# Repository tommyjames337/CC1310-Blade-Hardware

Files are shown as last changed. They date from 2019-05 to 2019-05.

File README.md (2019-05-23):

# CC1310-Blade-Hardware README

This repository contains the crucial design files for the CC1310 Blade (Rev D). Note that the Rev D board is functionally
identical to the Rev C board. It will work with all CC1310 Blade Rev C demo projects.

The files in this project should be organized accordingly in order to open the project correctly in KiCad:

1) Place CC1310_Dev_Board_D into desired directory.

2) Stock.zip and CC1310.zip should be unpacked into the same directory that CC1310_Dev_Board_D was placed into.

After the project is correctly opened, you may have to correct the references to the footprint and schematic symbol files. Once these references are corrected, you may create gerber files and order PCBs from your favorite manufacturer.

The repository for CC1310 Blade software demos can be found here: https://github.com/mprost/CC1310-Blade-Demos

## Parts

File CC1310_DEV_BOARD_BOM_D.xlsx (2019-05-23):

Texas Instruments & University of Texas at Austin |  |  |  | Created: | 2019-05-01
Assembly BOM for CC1310_DEV_BOARD |  |  |  | Revision: | D
Bill of Materials
Item | Ref | Qty | Description | Mfg | Part Number | Price/unit | Price of Qty
1 | C2 | 1 | CAPACITOR, CERAMIC C0G/NP0, 3.3pF, 50V, -0.25pF/+0.25pF, -55DEGC/+125DEGC, 0402, SMD | Murata | GRM1555C1H3R3CA01J | $0.10000 | $0.10000
2 | C3 | 1 | DNI CAP |  |  |  | $0.00000
3 | C4, C6 | 2 | CAPACITOR, CERAMIC C0G/NP0, 12pF, 50V, -5%/+5%, -55DEGC/+125DEGC, 0402, SMD | Murata | GRM1555C1H120JA01D | $0.10000 | $0.20000
4 | C5 | 1 | CAP CER 330PF 50V X7R 0402 | Murata | GRM155R71H331MA01D | $0.19000 | $0.19000
5 | C1, C7, C8, C9, C11, C14, C15, C16 | 8 | CAP CER 0.1UF 6.3V X5R 0402 | Murata | GRM152R60J104KE19D | $0.24000 | $1.92000
6 | C10 | 1 | CAP CER 1UF 10V X7S 0402 | Murata | GCM155C71A105KE38D | $0.18000 | $0.18000
7 | C12, C13 | 2 | CAP CER 22UF 6.3V X5R 0402 | Samsung Electro-Mechanics | CL05A226MQ5N6J8 | $0.56000 | $1.12000
8 | C17, C19 | 2 | CAP CER 2.2UF 6.3V X6S 0402 | Murata | GRM155C80J225KE95J | $0.13000 | $0.26000
9 | C18 | 1 | CAP CER 15PF 50V C0G/NP0 0402 | Murata | GJM1555C1H150JB01D | $0.29000 | $0.29000
10 | C20 | 1 | CAP CER 100PF 50V 0402 | Murata | GCM1555C1H101FA16D | $0.13000 | $0.13000
11 | C21, C22 | 2 | CAP CER 10UF 6.3V 0402 | Murata | GRM155C60E106ME16D | $0.20000 | $0.40000
12 | U3 | 1 | TVS DIODE 5.5V 6SON | Texas Instruments | TPD4E004DRYR | $0.62000 | $0.62000
13 | D1 | 1 | Red 630nm LED Indication - Discrete 2V 0603 (1608 Metric) | ROHM Semiconductor | SML-P12U2TT86R | $0.52000 | $0.52000
14 | D2, D3 | 2 | Green 560nm LED Indication - Discrete 2V 0603 (1608 Metric) | ROHM Semiconductor | SML-P13PTT86R | $0.57000 | $1.14000
15 | D4 | 1 | DIODE SCHOTTKY 20V 1A SOD123FL | ON Semiconductor | MBR120VLSFT1G | $0.39000 | $0.39000
16 | D5 | 1 | Orange 560nm LED Indication - Discrete 2V 0603 (1608 Metric) | ROHM Semiconductor | SML-P12DTT86R | $0.42000 | $0.42000
17 | D6 | 1 | Board Mount Temperature Sensors Low VTG Prec Vout 2.7-5.5V | Analog Devices | TMP36GT9Z | $1.40000 | $1.40000
18 | J1 | 1 | HEADER 16 PIN SIL VERTICAL SOCKET TIN | Harwin | M20-7821642 | $1.99000 | $1.99000
19 | J2 | 1 | HEADER 12 PIN SIL VERTICAL SOCKET TIN | Harwin | M20-7821246 | $1.42000 | $1.42000
20 | J3 | 1 | HEADER 4 PIN SIL VERTICAL SOCKET TIN | Harwin | M20-7820446 | $0.78000 | $0.78000
21 | J4 | 1 | .050" X .050 TERMINAL STRIP | SAMTEC | FTSH-105-01-F-DV-K-TR | $2.07400 | $2.07400
22 | J5 | 1 | CONNECTOR, USB, FEMALE, RIGHT ANGLE, 1 ROW, 5 PINS, PITCH 0.65mm, SMD | Molex, LLC | 1051640001 | $0.46304 | $0.46304
23 | J6 | 1 | CONN JSC RCPT STR 50 OHM SMD | Murata | MM5829-2700RJ4 | $0.63000 | $0.63000
24 | J7 | 1 | JST-PH Battery Connector for Li-Ion Batteries | Adafruit | 1769 | $0.75000 | $0.75000
25 | J8 | 1 | Coin Cell Battery Holders SFC MNT FOR CR1220 | Renata | SMTU1220-LF | $0.83000 | $0.83000
26 | L1 | 1 | FIXED IND 18NH 350MA 460 MOHM | Murata | LQG15HS18NJ02D | $0.10000 | $0.10000
27 | L2 | 1 | DNI IND |  |  |  | $0.00000
28 | L3 | 1 | TRANSFORMER, RF, BALUN, 770MHz TO 928MHz, UNBALANCED:50 Ohm, SMD | JOHANSON TECHNOLOGY | 0850BM14E0016 | $0.55000 | $0.55000
29 | L4 | 1 | FERRITE BEAD 1.5 KOHM 0603 1LN | Murata | BLM18HE152SN1D | $0.21000 | $0.21000
30 | L5 | 1 | FIXED IND 6.8UH 550MA 250 MOHM | TDK | MLZ2012N6R8LT000 | $0.14000 | $0.14000
31 | R1, R2, R14 | 3 | RES SMD 180 OHM 5% 1/16W 0402 | Vishay Dale | CRCW0402180RJNED | $0.10000 | $0.30000
32 | R3, R4 | 2 | DNI RES |  |  |  | $0.00000
33 | R5 | 1 | RES SMD 2.2K OHM 5% 1/5W 0402 | Vishay Dale | CRCW04022K20JNEDHP | $0.14000 | $0.14000
34 | R6, R8 | 2 | RES 3.3K OHM 5% 1/16W 0402 | Vishay Dale | CRCW04023K30JNEDC | $0.10000 | $0.20000
35 | R7, R10, R17 | 3 | RES SMD 100K OHM 5% 1/16W 0402 | Vishay Dale | CRCW0402100KJNEDC | $0.10000 | $0.30000
36 | R9, R13 | 2 | RES SMD 100 OHM 5% 1/16W 0402 | Vishay Dale | CRCW0402100RJNEDC | $0.10000 | $0.20000
37 | R11 | 1 | RES SMD 51K OHM 5% 1/16W 0402 | Vishay Dale | CRCW040251K0JNED | $0.10000 | $0.10000
38 | R12 | 1 | RES SMD 30K OHM 5% 1/16W 0402 | Vishay Dale | CRCW040230K0JNED | $0.10000 | $0.10000
39 | R15, R16 | 2 | DNI RES SMD 0 OHM 5% 1/16W 0402 | Vishay Dale |  |  | $0.00000
40 | R18 | 1 | RES SMD 274 OHM 5% 1/10W 0402 | TE Connectivity | RP73PF1E274RBTDF | $0.26000 | $0.26000
41 | R19 | 1 | RES SMD 10K OHM 5% 1/16W 0402 | Vishay Dale | CRCW040210K0JNEDC | $0.10000 | $0.10000
42 | SW1, SW2 | 2 | Switch, Tact 6mm SMT, 160gf | Omron | B3U-1000P | $1.00000 | $2.00000
43 | U1 | 1 | IC, Microcontroller, Texas CC1310, 128kB, 1.8V to 3.8V, VQFN48-EP, SMD | Texas Instruments | CC1310F128RGZ | $6.65000 | $6.65000
44 | U2 | 1 | IC, ANALOG, ULTRALOW-NOISE, HIGH PSRR, FAST, RF, 1A LOW-DROPOUT LINEAR REGULATORS, VIN:2.7V TO 5.5V, VOUT:1.2V TO 5.5V, SON8, SMD | Texas Instruments | TPS79601DRBR | $3.09000 | $3.09000
45 | U4 | 1 | TVS DIODE 5.5V 8UQFN | Texas Instruments | TPD6E004RSER | $0.65000 | $0.65000
46 | U5 | 1 | IC FLASH 8M SPI 33MHZ 8USON | Macronix | MX25R8035FZUIL0 | $1.13000 | $1.13000
47 | U6 | 1 | Battery Management Charge mgnt contr | Microchip Technology | MCP73831T-2ACI_OT | $0.57000 | $0.57000
48 | Y1 | 1 | CRYSTAL 32.7680KHZ 7.0PF SMT | EPSON | FC-135R 32.7680KA-AG3 | $0.59000 | $0.59000
49 | Y2 | 1 | CRYSTAL 24.0000MHZ 9PF SMD | EPSON | TSX-3225 24.0000MF15X-AC3 | $0.36000 | $0.36000
50 |  | 1 | PCB (0.9” X 2”) (BLANK) | JLCPCB |  | $2.00000 | $2.00000
51 |  | 1 | Lithium Ion Polymer Battery - 3.7v 100mAh | Adafruit | 1570 | $5.95000 | $5.95000
52 |  | 1 | CR1220 Coin Cell Battery | Murata | CR1220 | $1.22000 | $1.22000
 | TOTAL |  |  |  |  |  | $43.90704

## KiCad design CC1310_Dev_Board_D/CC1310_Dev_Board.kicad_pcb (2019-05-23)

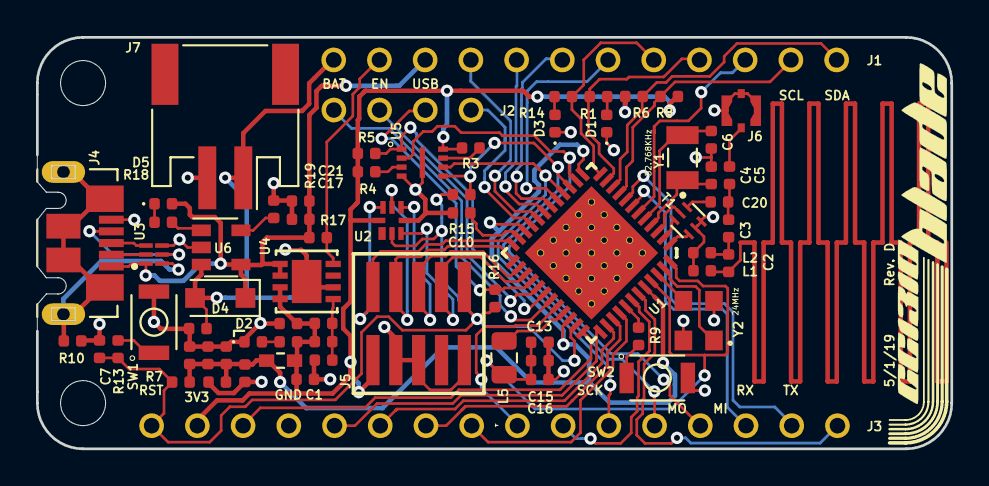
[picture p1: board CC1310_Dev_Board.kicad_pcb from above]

Board: 2 copper layers, 50.8 x 22.9 mm, 71 parts (1 on the bottom side), 69 nets.

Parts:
C1: 0.1uF; C_0402_1005Metric
C2: 3.3pF; C_0402_1005Metric
C3: DNM_0402; C_0402_1005Metric
C4, C6: 12pF; C_0402_1005Metric
C5: 330pF; C_0402_1005Metric
C7, C8, C9, C11, C14, C15, C16: 100nF; C_0402_1005Metric
C10: 1uF; C_0402_1005Metric
C12, C13: 22uF; C_0402_1005Metric
C17, C19: 2.2uF; C_0402_1005Metric
C18: 15pF; C_0402_1005Metric
C20: 100pF; C_0402_1005Metric
C21, C22: 10uF; C_0402_1005Metric
D1: SML-P12U2TT86R; LED_0402_1005Metric
D2, D3: SML-P13PTT86R; LED_0402_1005Metric
D4: MBR120; D_SOD-123F
D5: SML-P12DTT86R; LED_0402_1005Metric
J1: 68685-312LF; 68685-312LF-BLADE
J2: 68685-304LF; 68685-304LF-BLADE
J3: 68685-316LF; 68685-316LF-BLADE
J4: 105164-0001; MOLEX_105164-0001
J5: SAMTEC-FTSH-105-01-X-DV
J6: MM5829-2700RJ4; MURATA_MM5829-2700RJ4
J7: JST-PH; JST_PH_S2B-PH-SM4-TB_1x02-1MP_P2.00mm_Horizontal
J8: SMTU1220-LF; SMTU1225LF
L1: 18nH; L_0402_1005Metric
L2: DNM; L_0402_1005Metric
L4: BLM18HE152SN1D; INDC1608X95
L5: 6.8µH; L_0805_2012Metric
MH1, MH2: MountingHole; MountingHole_2.5mm
R1, R2, R14: 180; R_0402_1005Metric
R3, R4: DNI; R_0402_1005Metric
R5: 2.2K; R_0402_1005Metric
R6, R8: 3.3K; R_0402_1005Metric
R7, R10, R17: 100K; R_0402_1005Metric
R9, R13: 100; R_0402_1005Metric
R11: 51K; R_0402_1005Metric
R12: 30K; R_0402_1005Metric
R15, R16: 0; R_0402_1005Metric
R18: 274; R_0402_1005Metric
R19: 10K; R_0402_1005Metric
SW1, SW2: B3U-1000P; SW_B3U-1000P
T1: 0850BM14E0016T; INDCAF50P160X80X70-6N
U1: CC1310F64RGZT; QFN50P700X700X100-49N
U2: TPD6E004RSER
U3: TPD4E004DRYR
U4: TPS79601DRBR
U5: MX25R8035FZUIL0; USON-8L
U6: MCP73831T-2ACI_OT; SOT-23-5
Y1: FC-135R_32.7680KA-AG0; XTAL_FC-135R_32.7680KA-AG0
Y2: 24MHz; OSCSC320X250X100N

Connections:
AIO_23: J3.A3, U1.36
AIO_24: J3.A5, U1.37
AIO_25: J3.A6, U1.38
AIO_26: J3.A7, U1.39
AIO_27: J3.A8, U1.40
CC1310_RESET: C7.2, J3.A1, J5.10, R7.1, R13.2, R15.2, R16.2, U1.35, U2.2
CC1310_TCK: J5.4, U1.25, U2.6
CC1310_TMS: J5.2, U1.24, U2.7
CC1310_VDD: C1.1, C18.1, C19.1, J3.A2, J5.1, L4.1, R2.2, R3.1, R4.1, R5.1, R6.2, R8.2, R11.1, U2.8, U4.3, U4.4, U5.8
DIO_1: J1.A10, U1.6
DIO_2_UART_RX: J3.A14, U1.7
DIO_3_UART_TX: J3.A15, U1.8
DIO_4_SCL: J1.A11, R8.1, U1.9
DIO_5_SDA: J1.A12, R6.1, U1.10
DIO_8_MISO: J3.A13, U1.14, U5.2
DIO_9_MOSI: J3.A12, R15.1, U1.15, U5.5
DIO_10_SCLK: J3.A11, U1.16, U5.6
DIO_11: J1.A7, U1.17
DIO_12: J1.A6, U1.18
DIO_13: J1.A5, U1.19
DIO_14: J1.A4, U1.20
DIO_15: J2.A1, U1.21
DIO_16: J5.6, U1.26, U2.5
DIO_17: J5.8, U1.27, U2.3
DIO_18: J2.A2, R16.1, U1.28
DIO_19: J2.A3, U1.29
DIO_20: R5.2, U1.30, U5.1
DIO_21: J2.A4, U1.31
DIO_22: J3.A9, U1.32
DIO_29: J3.A10, U1.42
DIO_30: J3.A16, U1.43
EN: J1.A2, R17.1, U4.8
GND: C1.2, C4.1, C6.1, C7.1, C8.2, C9.2, C10.2, C11.2, C12.2, C13.2, C14.2, C15.2, C16.2, C17.2, C19.2, C21.2, C22.2, D1.1, D2.1, D3.1, J3.A4, J4.5, J5.3, J5.5, J5.9, J6.2, J6.3, J6.4, J7.2, J8.2, L1.2, L2.2, R10.2, R12.2, R19.2, SW1.2, SW2.2, T1.5, T1.6, U1.49, U1.50, U1.51, U1.52, U1.53, U1.54, U1.55, U1.56, U1.57, U1.58, U1.59, U1.60, U1.61, U1.62, U1.63, U1.64, U1.65, U1.66, U1.67, U1.68, U1.69, U1.70, U1.71, U1.72, U1.73, U1.74, U2.4, U3.3, U4.6, U4.9, U5.4, U5.9, U6.2, Y2.2, Y2.4
LED_USER_GREEN: J1.A8, R14.2, U1.12
LED_USER_RED: J1.A9, R1.2, U1.11
unnamed: C2.2, L1.1
unnamed: C2.1, C3.2, L2.1
unnamed: C4.2, U1.4, Y1.1
unnamed: C5.2, J6.1
unnamed: C6.2, U1.5, Y1.2
unnamed: C10.1, U1.23
unnamed: C13.1, C15.1, C16.1, L5.2, U1.45, U1.48
unnamed: C18.2, R11.2, R12.1, U4.5
unnamed: C20.1, T1.1
unnamed: C3.1, C5.1, C20.2
unnamed: D1.2, R1.1
unnamed: D2.2, R2.1
unnamed: D3.2, R14.1
unnamed: D5.1, R18.2
unnamed: J4.2, U3.5
unnamed: J4.3, U3.4
unnamed: J4.4, U3.2
unnamed: J4.SH1, J4.SH2, J4.SH3, J4.SH4, J4.SH5, J4.SH6, R10.1, U3.1
unnamed: L5.1, U1.33
unnamed: R3.2, U5.7
unnamed: R4.2, U5.3
unnamed: R9.1, SW2.1
unnamed: R13.1, SW1.1
unnamed: R18.1, U6.1
unnamed: R19.1, U6.5
unnamed: T1.2, U1.3
unnamed: T1.3, U1.2
unnamed: T1.4, U1.1
unnamed: U1.46, Y2.3
unnamed: U1.47, Y2.1
SW_USER: R9.2, U1.41
VBAT: C22.1, D4.2, J1.A1, J7.1, J8.1, U6.3
VBUS: C17.1, C21.1, D4.1, D5.2, J1.A3, J4.1, R17.2, U3.6, U4.1, U4.2, U6.4
VDD: C8.1, C9.1, C11.1, C12.1, C14.1, L4.2, R7.2, U1.13, U1.22, U1.34, U1.44

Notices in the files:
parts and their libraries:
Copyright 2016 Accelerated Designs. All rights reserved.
